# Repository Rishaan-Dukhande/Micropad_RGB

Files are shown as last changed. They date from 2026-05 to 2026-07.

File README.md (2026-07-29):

# Rishaan RGB micro hackpad

The RGB micro is a 2 key macropad with a joystick, an OLED Display, and one RGB LED - giving the user multiple ways to change an LED to any color and brightness they want! This serves as the first PCB I have created and is a great introductory project to develop PCB, CAD, and firmware skills for engineering! I created this project to develop these skills and enhance my engineering skills and knowledge. I have used RGBs and there is a color game called hues and cues, and this LED allows you to access a pallet just like the game, but in real life! Features, Images, and steps to recreate this project are listed below.
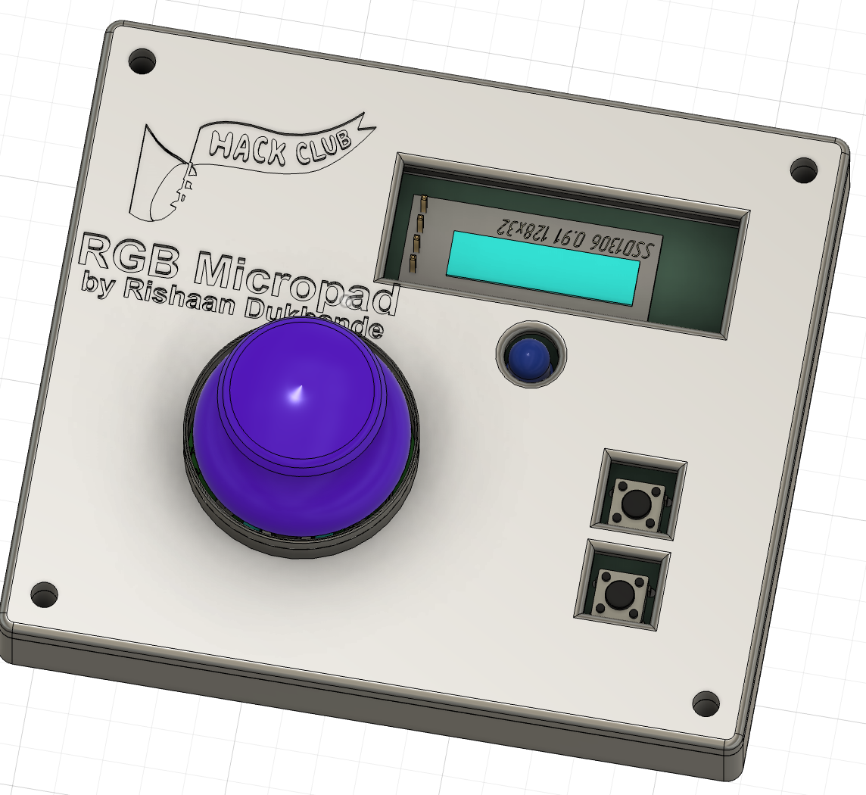
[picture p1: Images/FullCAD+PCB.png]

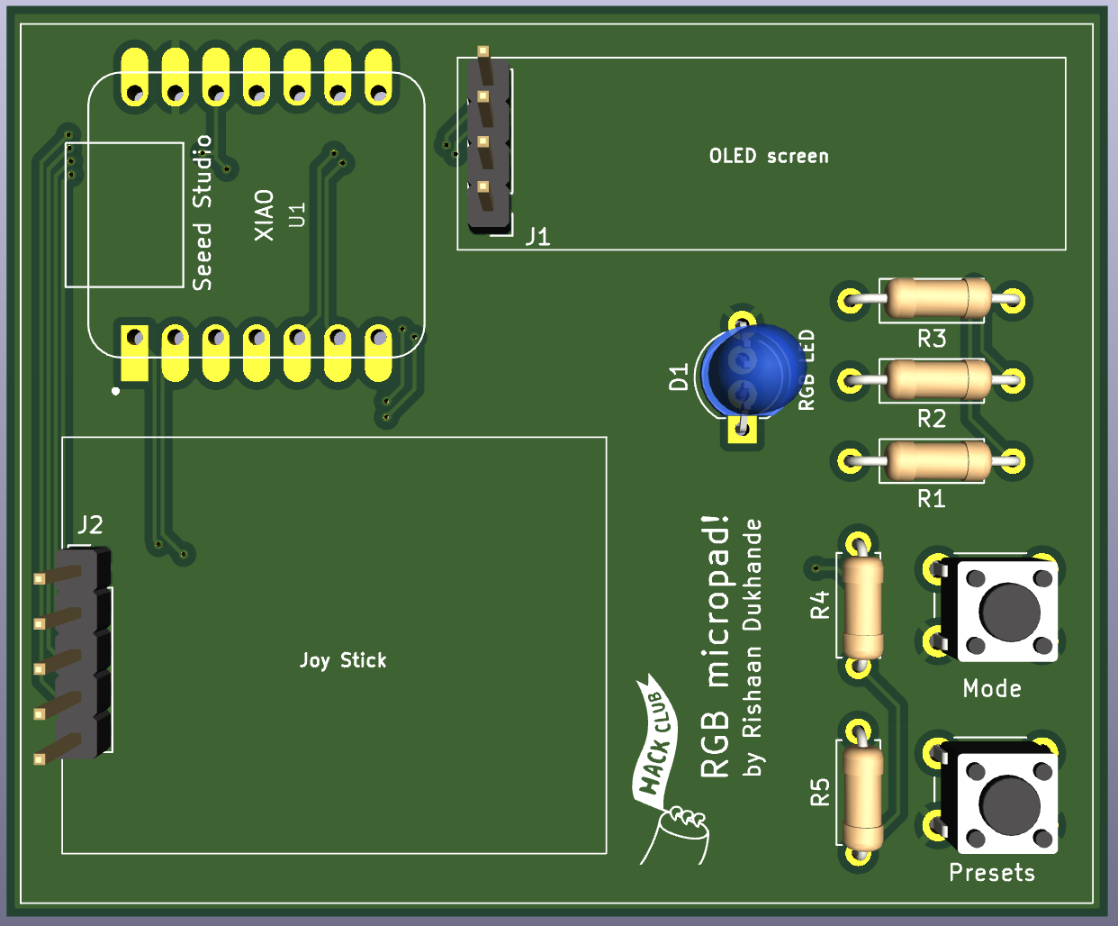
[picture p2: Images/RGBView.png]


# Demo

Video Title (https://www.youtube.com/watch?v=ukX_e_Ombvo)

## Features:

* Portable 3D case with openings for components and USB connection
* Seeeduino XIAO SAMD21 controller
* 1 RGB LED for bright color display
* 2 tactile switch buttons for modes and presets
* Small OLED screen that displays the current RGB value in real time.
* Joystick for smooth & dynamic brightness and color control

## How it works

The RGB Micropad is a mini RGB LED controller. The joystick navigates 
a full 360° color wheel — pushing in any direction changes the LED to 
that hue in real time. SW1 toggles between Color mode and Brightness 
mode, while SW2 cycles through 8 color presets. Pressing the joystick 
button activates Saturation mode, letting the user dial between vivid 
and pastel tones and creating a larger array of colors for the LED to
display. The OLED screen shows the current mode, color name, 
RGB values, and brightness percentage at all times.

## PCB

Here's my PCB! Kicad was used to create both the schematic and layout of the pcb.

### Schematic

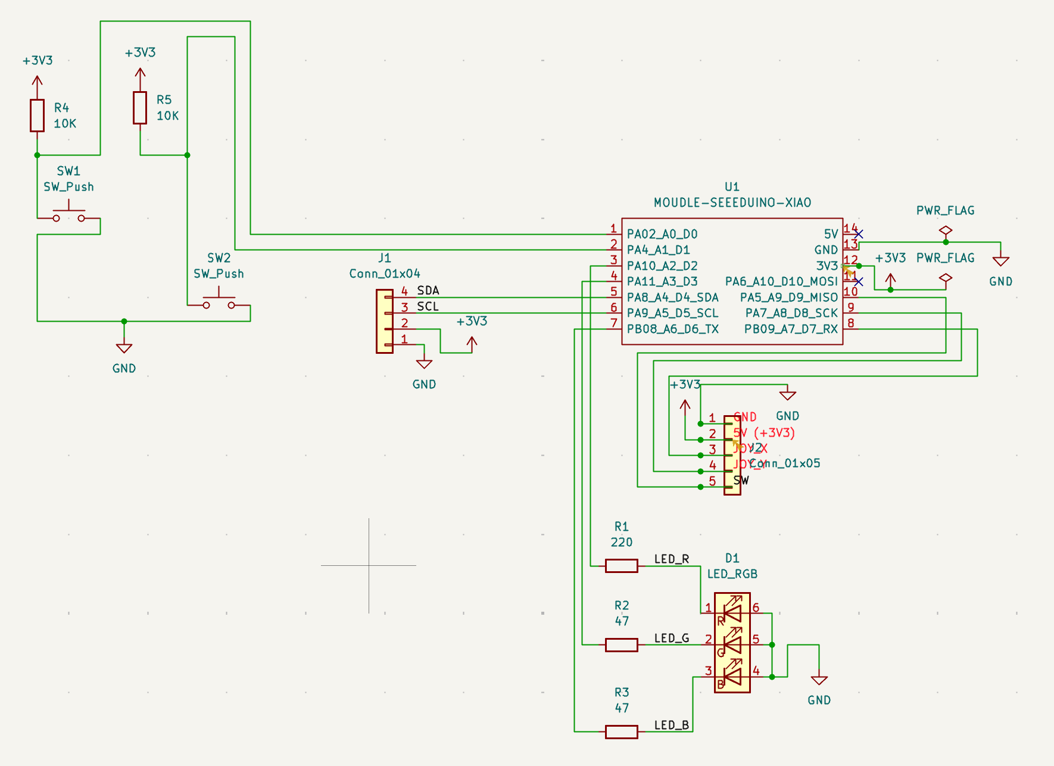
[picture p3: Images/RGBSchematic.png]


### PCB

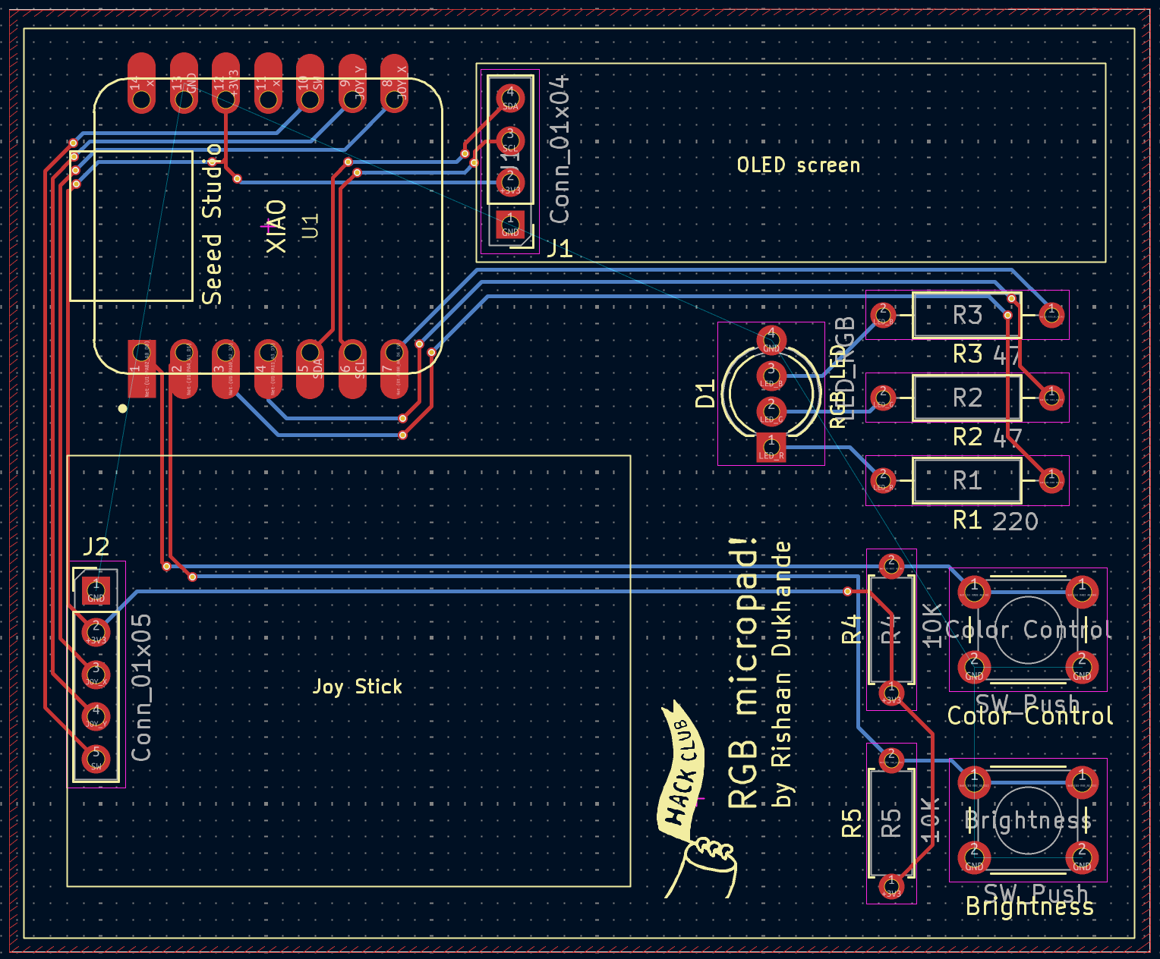
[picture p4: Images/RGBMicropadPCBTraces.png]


The 1x4 connector on the top is for connecting the Oled Screen (SSD1306 0.91" OLED I2C 128x32) The 1x5 connector on the bottom center of the pcb is for connecting the controling joystick

## Sizes and PCB Info

* Board size: 56.95mm x 68.85mm
* 2 layer PCB
* Designed in KiCad 9.0

## Firmware
Written in CircuitPython. The main.py file enables the user to have the following controls:
* SW1 → Toggle between Color mode and Brightness mode
* SW2 → Cycle through 8 color presets
* Joystick button → Toggle saturation mode on/off
* Joystick X/Y → Navigate color wheel (Color mode) or adjust brightness (Brightness mode)
* OLED display → Shows current mode, color name, RGB values, and brightness %

## BOM:

Here is everything used in the RGB micro hackpad. Note that most of the prices come in sets because components cost the least when they are bought in bulk.

| **Qty** | **Component** | **Note** | **Price** |
|:--:|:--:|:--:|:--:|
| 1 | Seeeduino XIAO SAMD21 | Main processor | [~$5.40](https://www.seeedstudio.com/Seeeduino-XIAO-Arduino-Microcontroller-SAMD21-Cortex-M0+-p-4426.html) |
| 1 | SSD1306 0.91" OLED I2C 128x32 | Displays brightness and color info | [~$7.99](https://www.amazon.com/gp/product/B079BN2J8V/ref=ewc_pr_img_4?smid=A1WZRPJ0MN58A9&th=1) |
| 1 | Analog thumbstick joystick module KY-023 | Joystick control | [~$7.99](https://www.amazon.com/gp/product/B0GWQ6KXYP/ref=ewc_pr_img_3?smid=A3S807LE0L63AP&psc=1) |
| 1 | RGB LED 5mm common cathode | LED that is being controlled | [~$8.99 (100 pack)](https://www.amazon.com/gp/product/B01C3ZZT8W/ref=ewc_pr_img_1?smid=A14FP9XIRL6C1F&th=1) |
| 2 | 10KΩ resistor | Pull up resistors for buttons | [~$8.99 (kit)](https://www.amazon.com/Elegoo-Values-Resistor-Assortment-Compliant/dp/B072BL2VX1) |
| 1 | 220Ω resistor | Red LED pin | [included in resistor kit](https://www.amazon.com/Elegoo-Values-Resistor-Assortment-Compliant/dp/B072BL2VX1) |
| 2 | 47Ω resistor | Green and Blue LED pins | [included in resistor kit](https://www.amazon.com/Elegoo-Values-Resistor-Assortment-Compliant/dp/B072BL2VX1) |
| 2 | Tactile push button 6x6mm | Control modes for joystick control | [~$5.99 (pack)](https://www.amazon.com/gp/product/B07VSNN9S2/ref=ewc_pr_img_2?smid=AJJYA8M5YMCKV&psc=1) |
| 1 | 2.54mm pin header 1x04 | OLED screen connector | [~$6.99 (pack)](https://www.amazon.com/MCIGICM-Header-2-54mm-Arduino-Connector/dp/B07PKKY8BX) |
| 1 | 2.54mm pin header 1x05 | Joystick connector | [included in pack above](https://www.amazon.com/MCIGICM-Header-2-54mm-Arduino-Connector/dp/B07PKKY8BX) |

## Steps to Reproduce

### Parts
Order the parts in the Bill of Materials. These will be soldered on the PCB manually later on (unless specified in JLCPCB)

### PCB Manufacturing
1. Download PCB/gerbers.zip (in PCB folder of repository)
2. Upload to JLCPCB or PCBWay (You can get grants from hackclub if you edit the PCB before upload!)
3. Place the order - remember to pick the least expensive shipping!

### Assembly

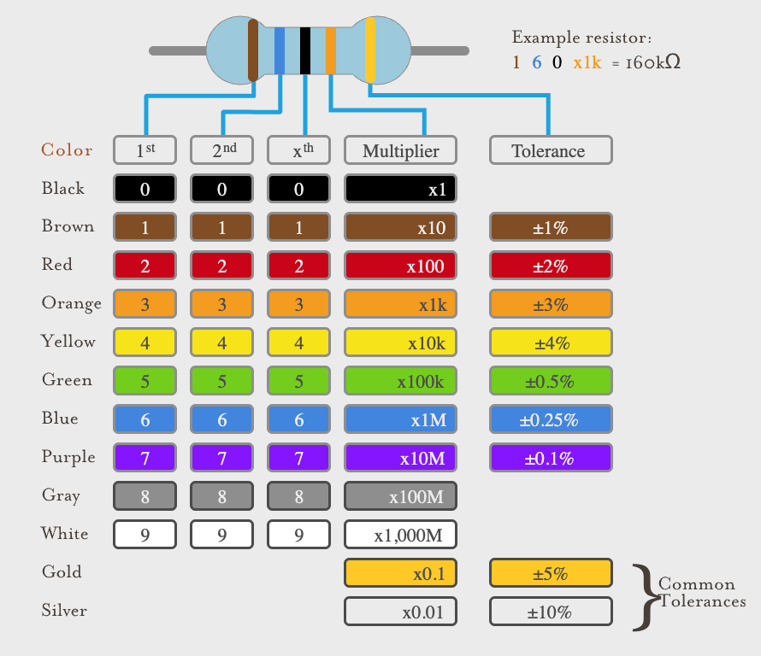
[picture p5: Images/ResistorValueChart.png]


1. Solder resistors R1-R5 onto the PCB. Utilize the following resistor values
2. Refer to the table above to read resistor values before incorporating them.
The table below has the resistor values with their placement on the PCB.

| **R#** | **Value** |
|:--:|:--:|
| R1 | 220Ω |
| R2 | 47Ω |
| R3 | 47Ω |
| R4 | 10KΩ |
| R5 | 10KΩ |
  
3. Solder RGB LED into the D1 slot on the PCB
4. Solder tactile switches SW1 and SW2.
5. Solder 5 pin header into the slot for the Joystick
6. Solder 4 pin header into the slot for the OLED screen
7. Solder XIAO SAMD21 on the top left of the board

### Flashing Instructions (Get firmware onto the PCB)
1. Copy or download the firmware as a .ino file and open it in arduino IDE
2. Use a USB-C transfer cable and plug it into the seedunio XAMD 21 and a computer
3. Upload the code using arduino IDE
4. The RGB Micropad will automatically begin to work (it can be plugged in directly to power)

### Verify your RGB Micropad works!
1. Plug in via USB (either computer of any electricity source)
2. OLED should show RGB Micropad splash screen
3. Move joystick to change LED color or brightness (depends on the mode you are on)
4. Press SW1 to toggle between modes!
   Mode 1: Color
   Mode 2: Brightness
5. Press SW2 to cycle through preset colors for LED
6. Press Joystick button to toggle saturation mode (This is an advanced mode for an additional array of colors)

## AI Usage
AI was used during the project as a step-by-step guide. The firmware was also written by AI.

## Devlog
### Session 1 — Schematic Design
The schematic was designed in Kicad. This included the following components:
1) XIAO SAMD21
2) RGB LED
3) Joystick module
4) OLED screen
5) Two tactile buttons

### Session 2 — PCB Layout
Note) This takes about 2 hrs for beginners
1) Layout of all components (If you are replicating, be creative and change locations of components).
2) Added GND copper pour so I don't have to route GND pins of every component
3) Routed the PCB connections between XIAO board and components
4) Created Silkscreen for aesthetics including Hack Club logo and component labels.

### Session 3 - Error with pullup resistors
1) Edited schematic by adding 10KΩ pullup resistors for both tactile switches
2) Used Ohm's law to calculate resistor values for RGB LED pins
   a) Blue and Green pins receive 47Ω resistors
   b) Red pin receives 220Ω resistors
   c) This occurs because they have different voltage requirements in order to power the color
3) Update PCB layout to include the resistors (2hrs).

### Session 4 — Firmware
1) Wrote CircuitPython firmware. This enables the PCB to have the following capabilities:
   a) Implemented color wheel for color mode control
   b) Brightness control from Joystick
   c) Mode navigation button to control both color and brightness with one Joystick
   d) Easily use joystick to change LED characteristics

### Session 5 — Case Design
Designed sandwich mount 3D-case in Fusion 360. The sandwich mount design can be found as the 5th mount in this [Different keyboard mounts](https://www.monsgeek.com/blog/comprehensive-guide-to-keyboard-mounting-styles/) document.

#### Bottom case (1hr)
1) Created bottom case with 0.4 mm clearance for PCB on all sides
2) Added 10mm thick walls all around board and 3.2mm diameter mounting holes
#### Top case (1 hr)
3) Measured placement of components on PCB and created openings
4) Added fillets to strengthen design and make it look good
5) Added project name, author, and hackclub svg logo

### Session 6 - README and Github Polish
1) Reviewed current github
2) Added devlog, images, and project info to the README.

### session 7 - Assembly (3-4 hrs)
1) Soldered components to the PCB
2) Re-designed the case to better fit PCB
3) Created Demo Video

## Extra stuff

I am ready to create more complex hackpads. Through this project, I was able to gain PCB making skills and refine my CAD skills. I am now confident that I can create electronic projects at a much faster pace with the use of these digital designing tools. If you have any project recommendations, please feel free to share them!

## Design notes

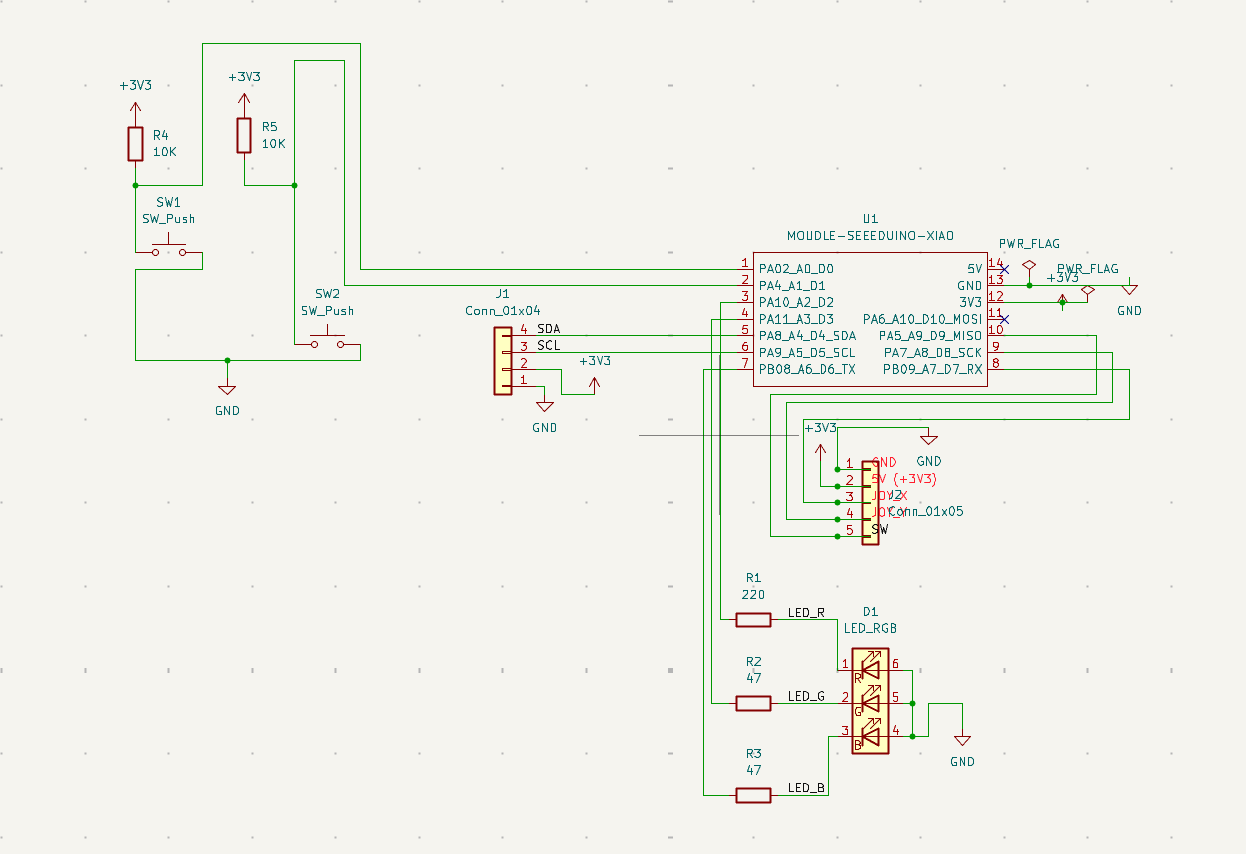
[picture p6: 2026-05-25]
Images/RGBMicropadSchematic.png

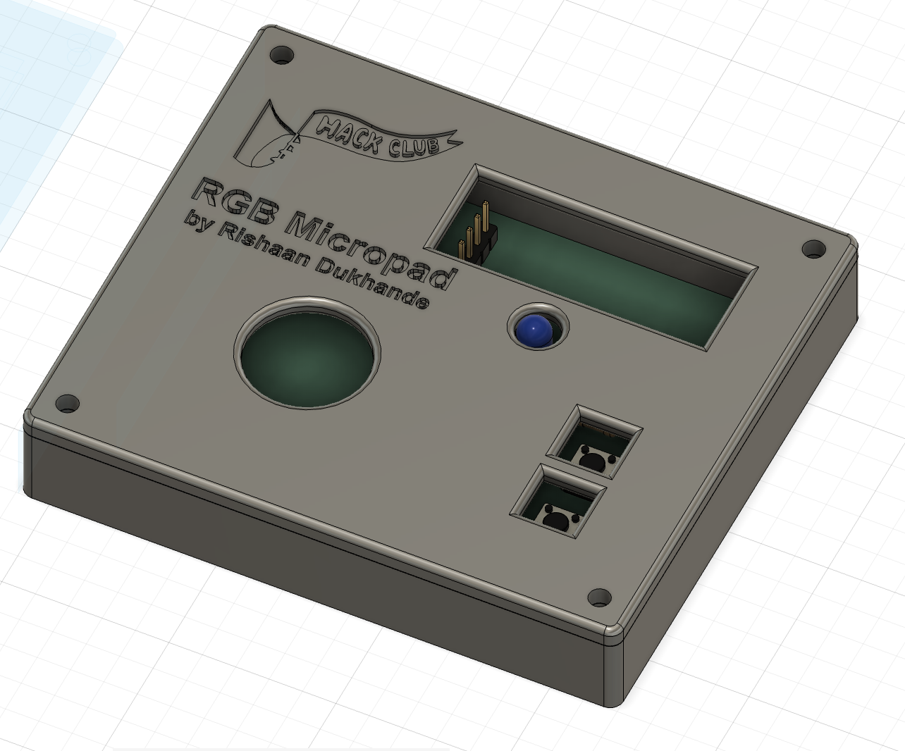
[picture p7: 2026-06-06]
Images/V1FullCase.png

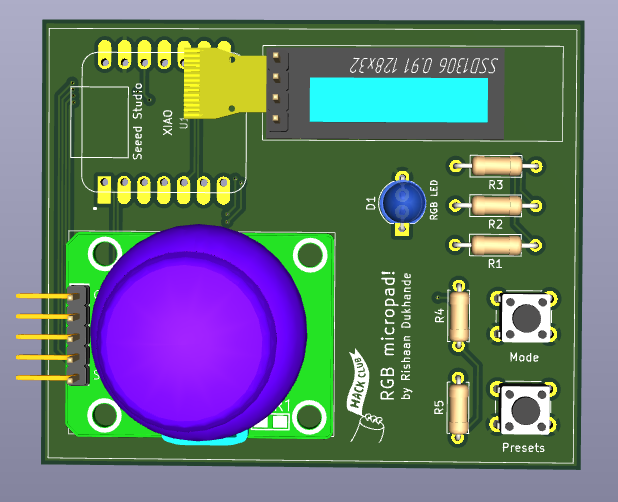
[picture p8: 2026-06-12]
Images/PCB+modules.png

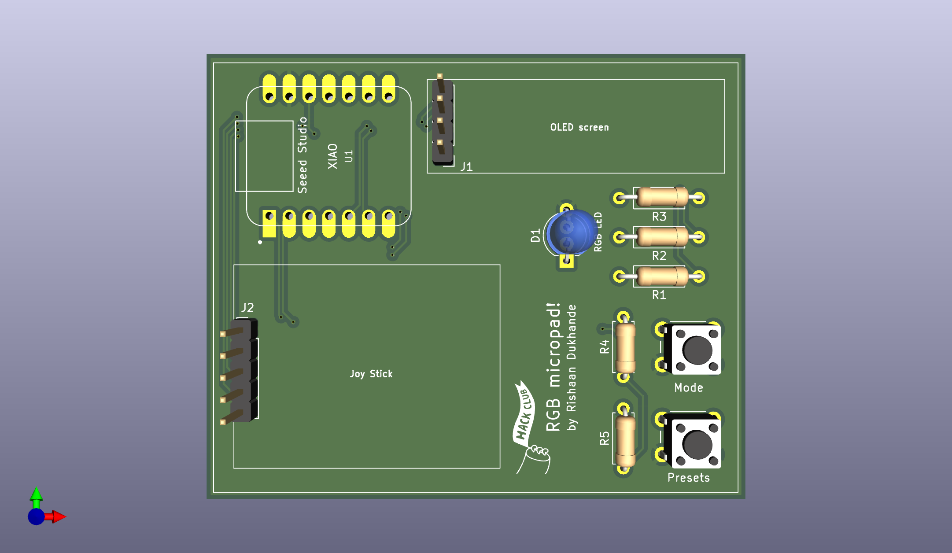
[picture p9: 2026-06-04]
PCB/rgbPCB.png

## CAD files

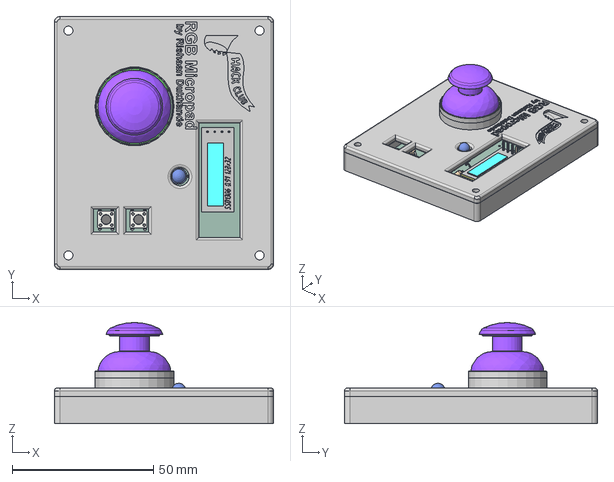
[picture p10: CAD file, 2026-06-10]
CAD/micropad_combined.step
77.8 x 89.7 x 35.8 mm

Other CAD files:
CAD/rgb_micropad_case.f3z

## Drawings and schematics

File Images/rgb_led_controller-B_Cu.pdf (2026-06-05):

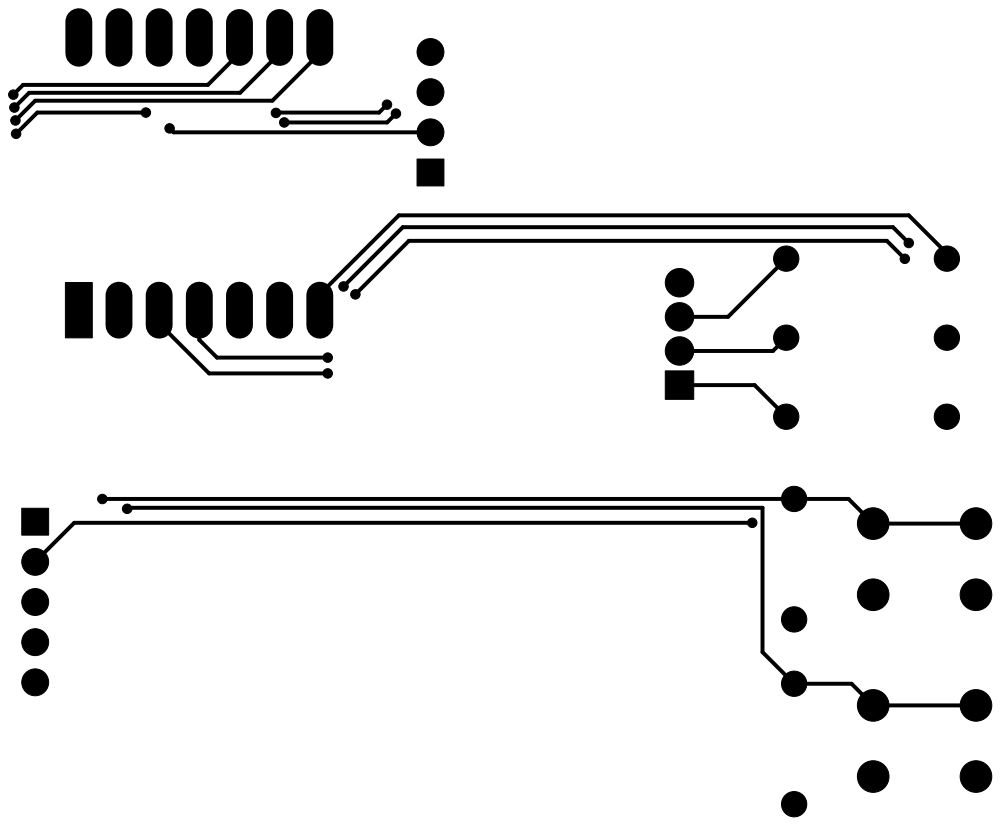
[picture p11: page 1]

Id: 2/10 Title: File: rgb_led_controller.kicad_pcb Sheet:

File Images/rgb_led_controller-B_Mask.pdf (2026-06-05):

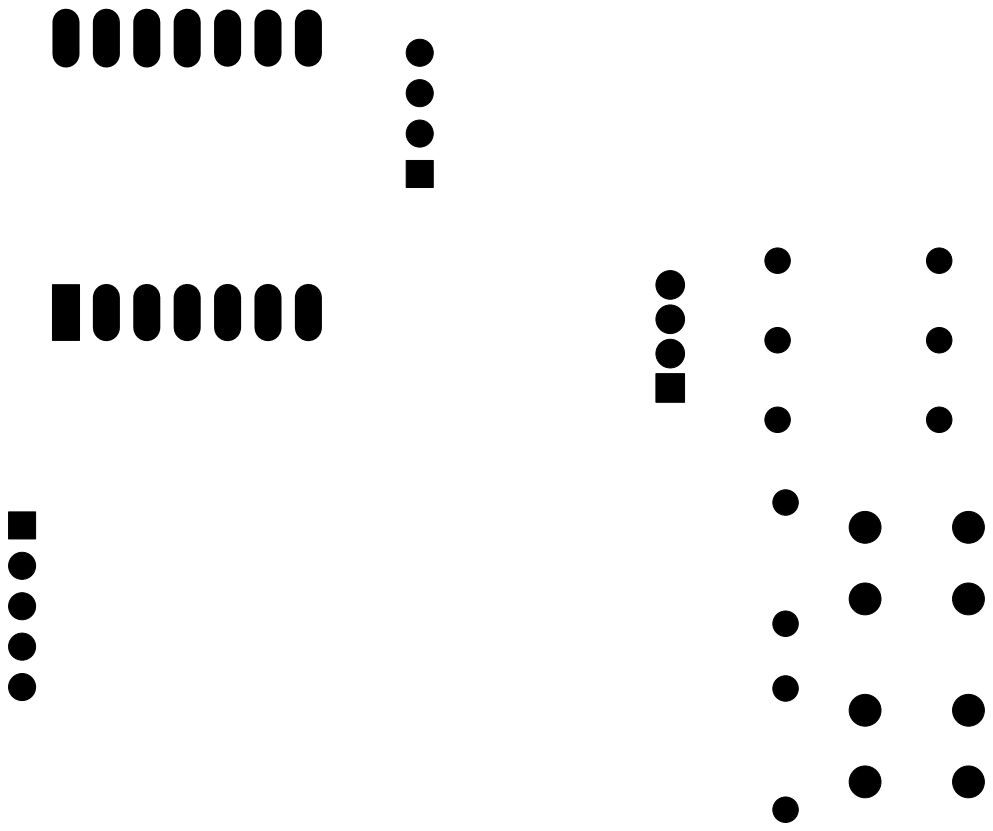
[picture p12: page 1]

Id: 8/10 Title: File: rgb_led_controller.kicad_pcb Sheet:

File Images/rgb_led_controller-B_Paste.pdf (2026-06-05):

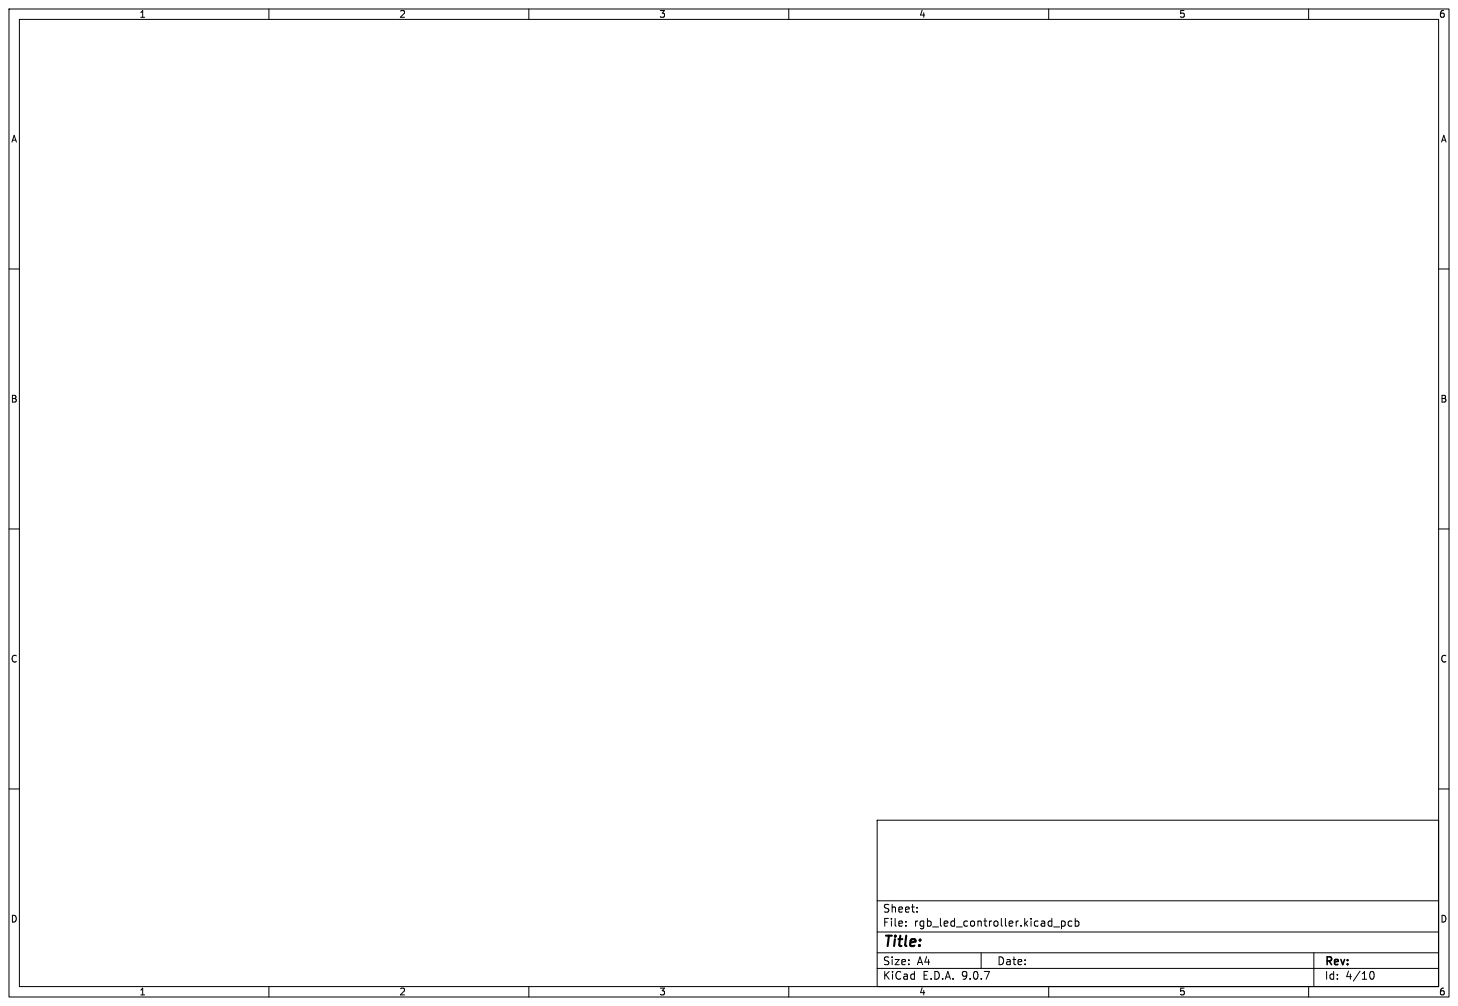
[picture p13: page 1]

Id: 4/10 Title: File: rgb_led_controller.kicad_pcb Sheet:

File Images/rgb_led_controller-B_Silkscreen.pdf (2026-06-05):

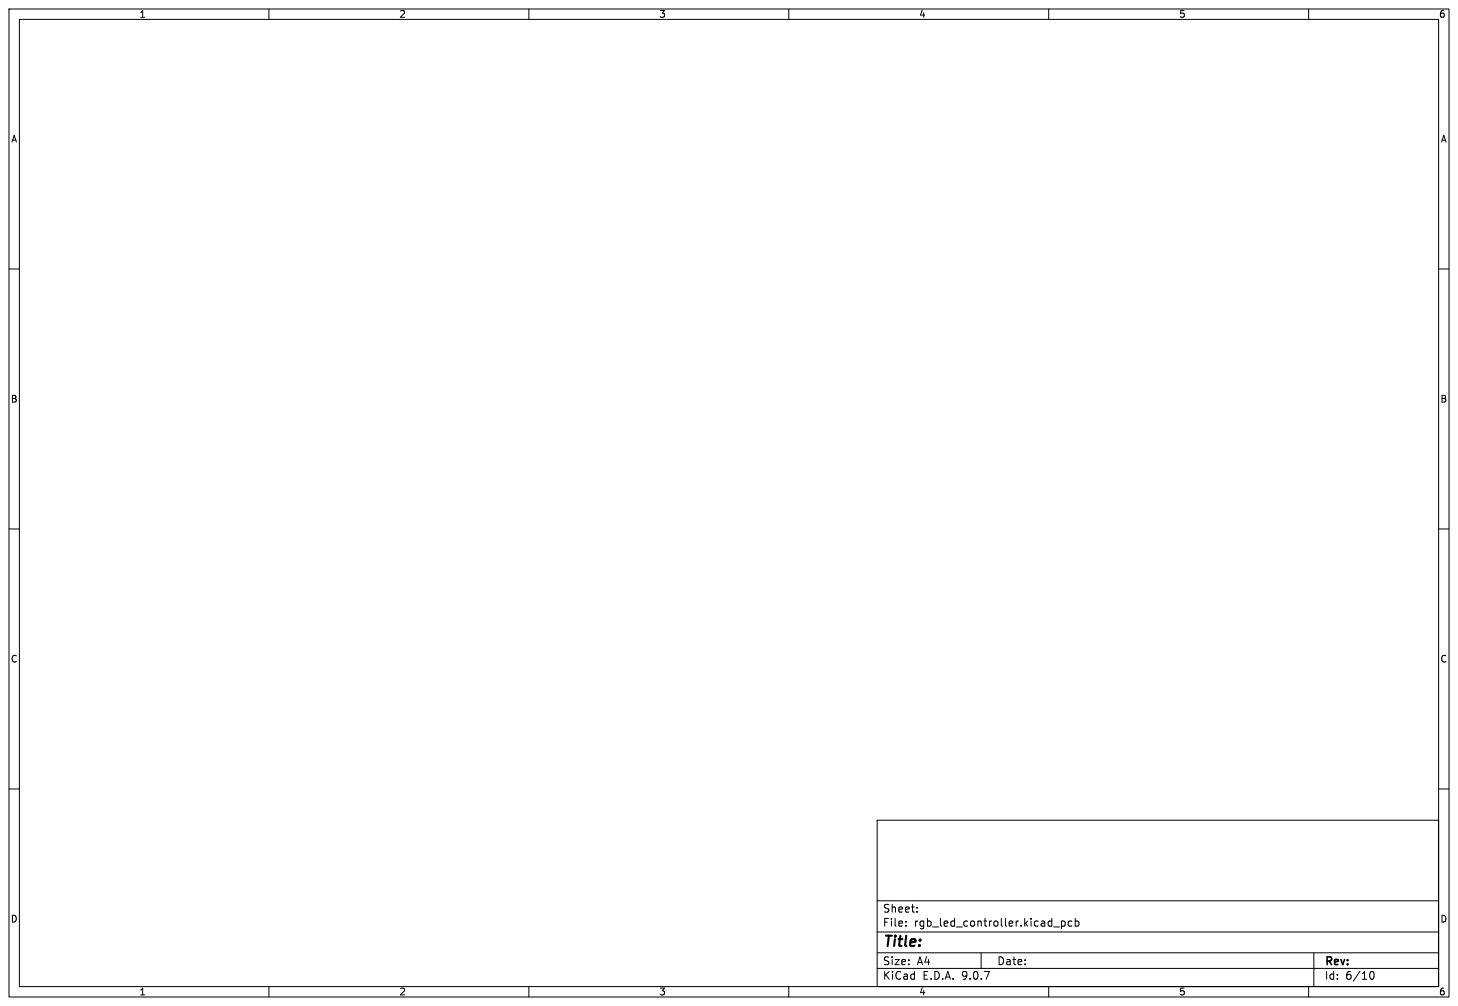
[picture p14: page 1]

Id: 6/10 Title: File: rgb_led_controller.kicad_pcb Sheet:

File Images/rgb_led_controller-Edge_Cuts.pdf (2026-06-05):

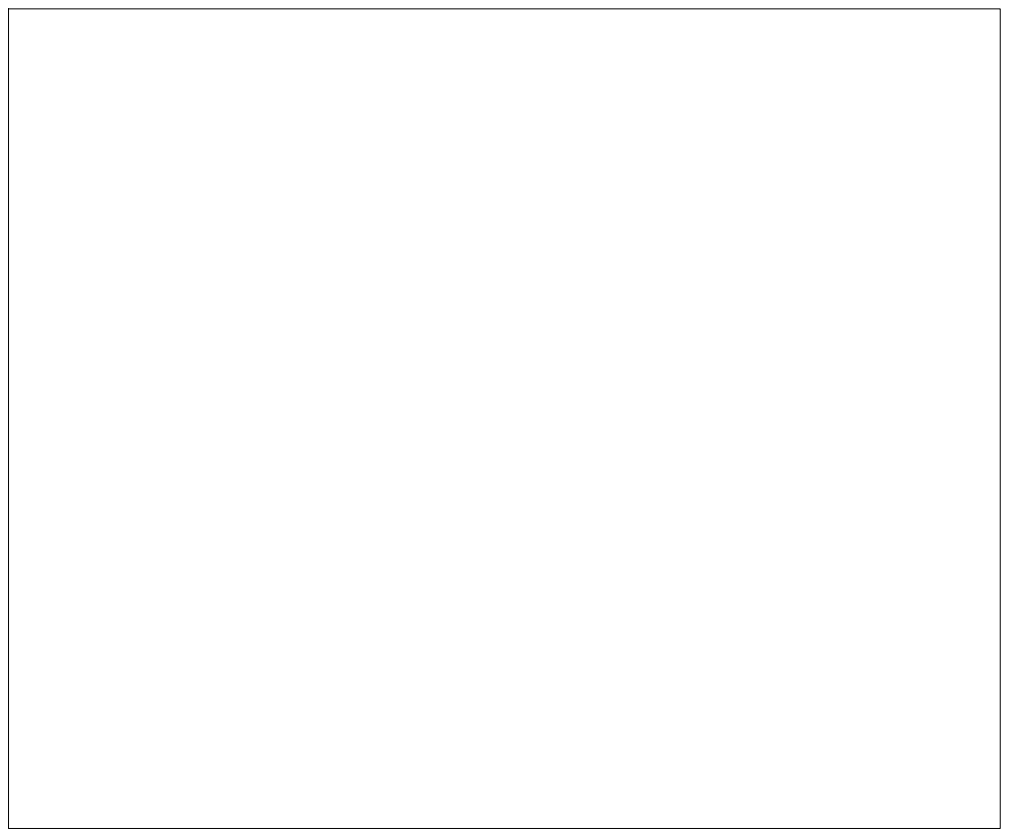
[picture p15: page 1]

Id: 9/10 Title: File: rgb_led_controller.kicad_pcb Sheet:

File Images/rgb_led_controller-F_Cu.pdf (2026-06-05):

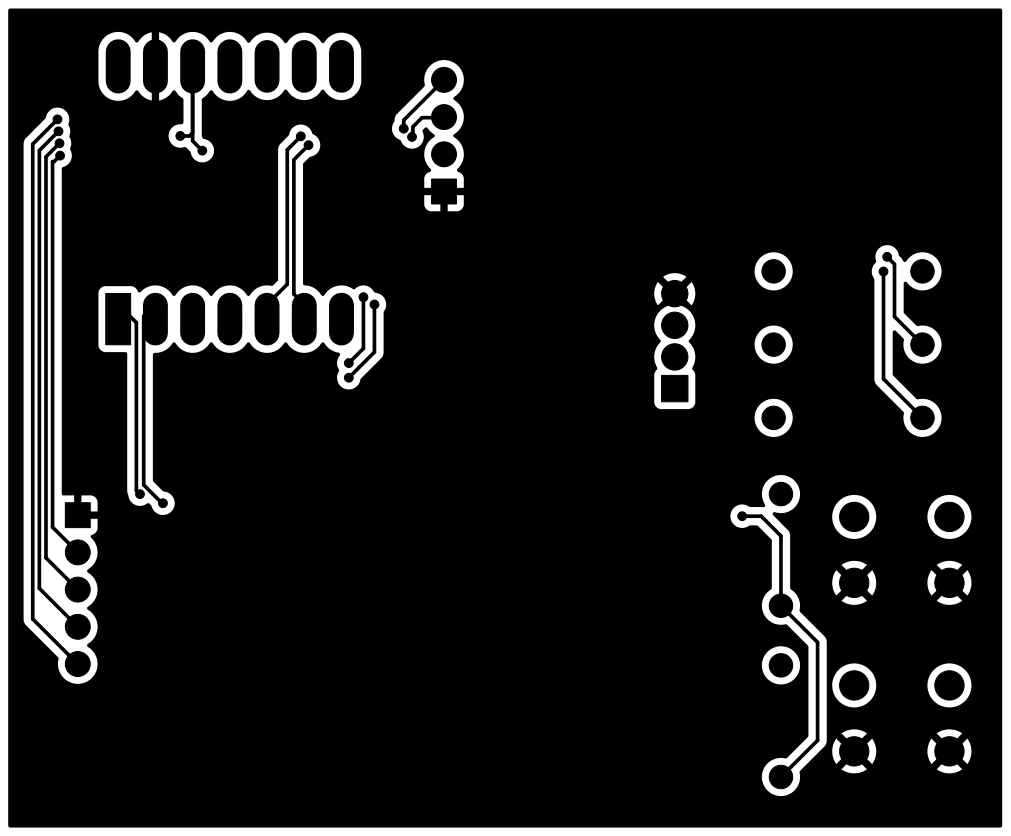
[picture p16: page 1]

Id: 1/10 Title: File: rgb_led_controller.kicad_pcb Sheet:

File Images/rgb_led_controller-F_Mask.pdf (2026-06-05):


Id: 7/10 Title: File: rgb_led_controller.kicad_pcb Sheet:

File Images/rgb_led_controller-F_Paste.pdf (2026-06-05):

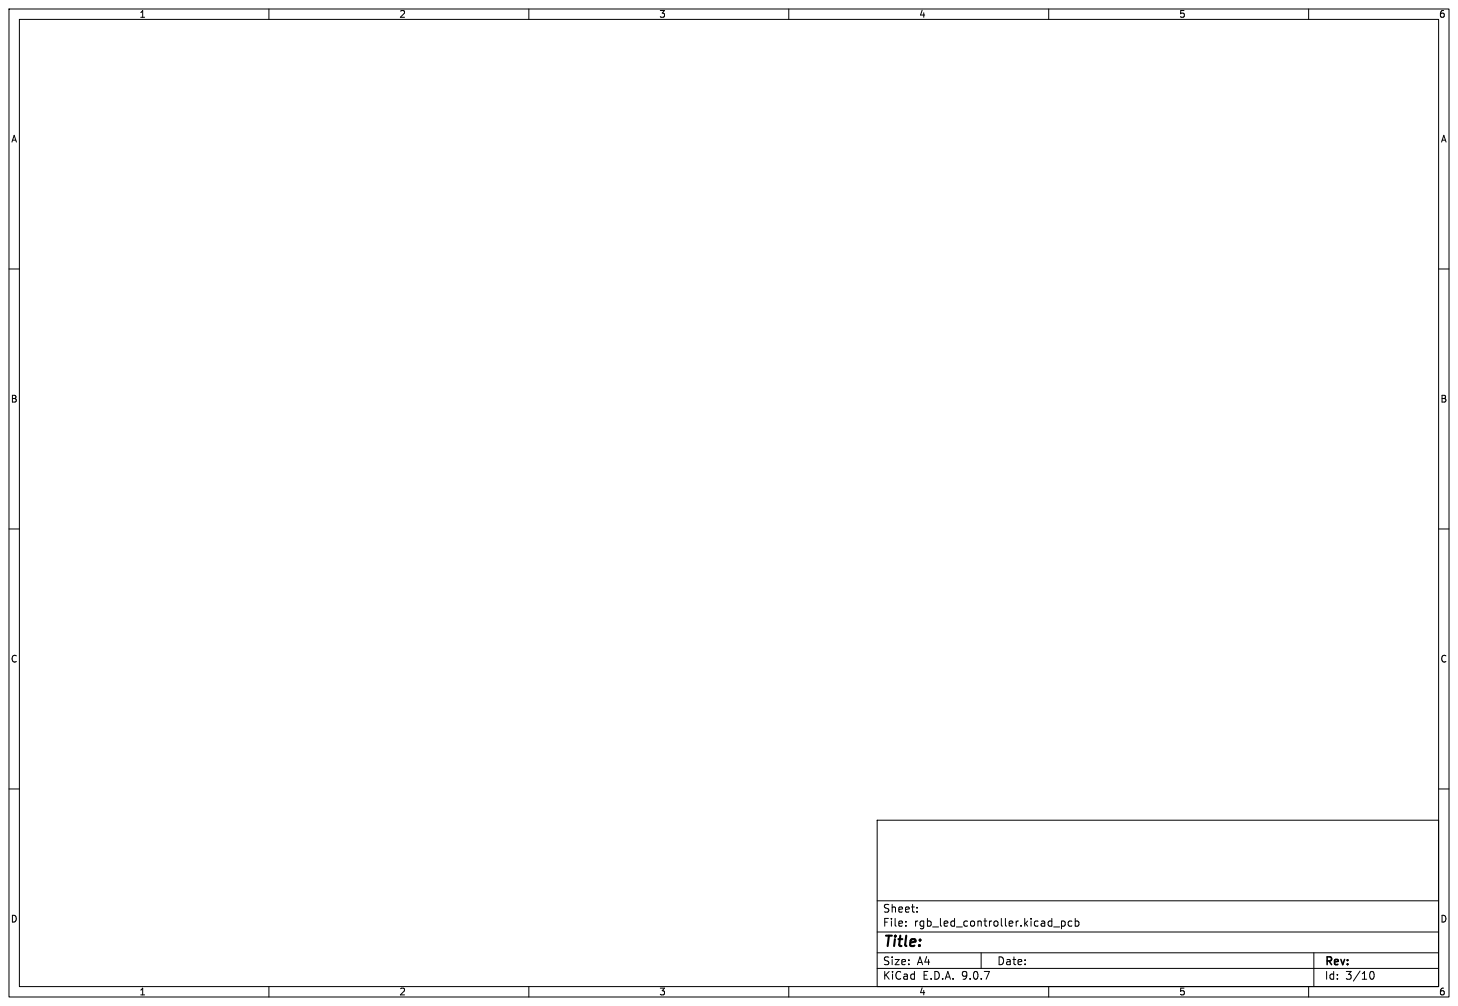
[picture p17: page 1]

Id: 3/10 Title: File: rgb_led_controller.kicad_pcb Sheet:

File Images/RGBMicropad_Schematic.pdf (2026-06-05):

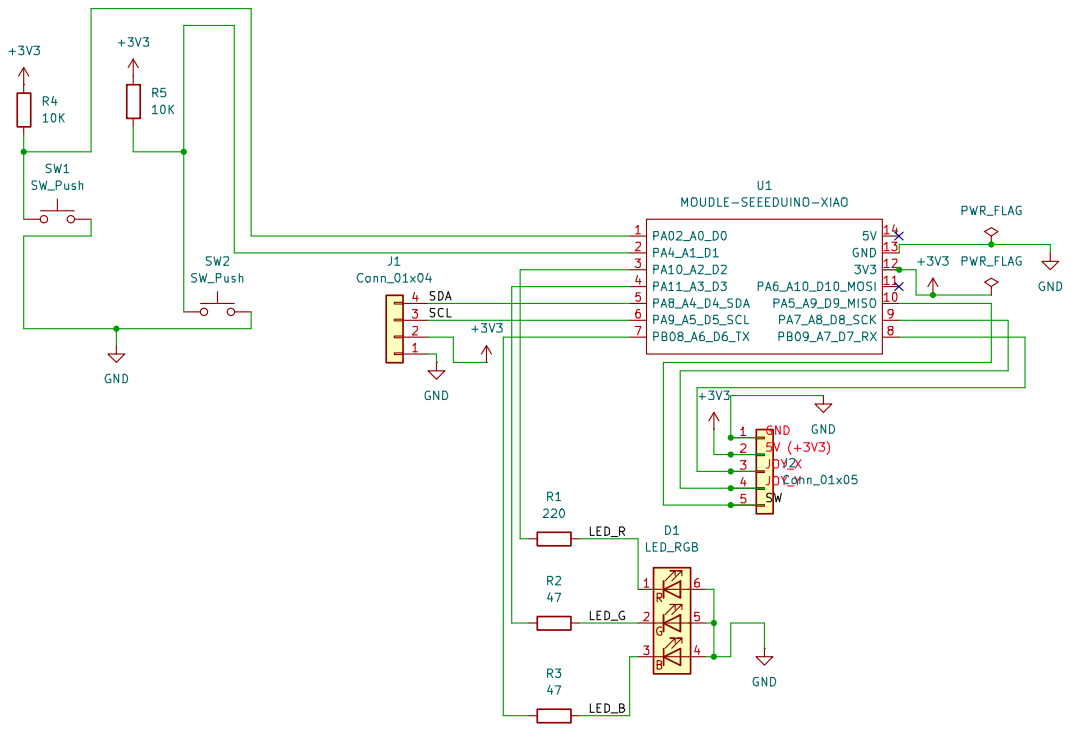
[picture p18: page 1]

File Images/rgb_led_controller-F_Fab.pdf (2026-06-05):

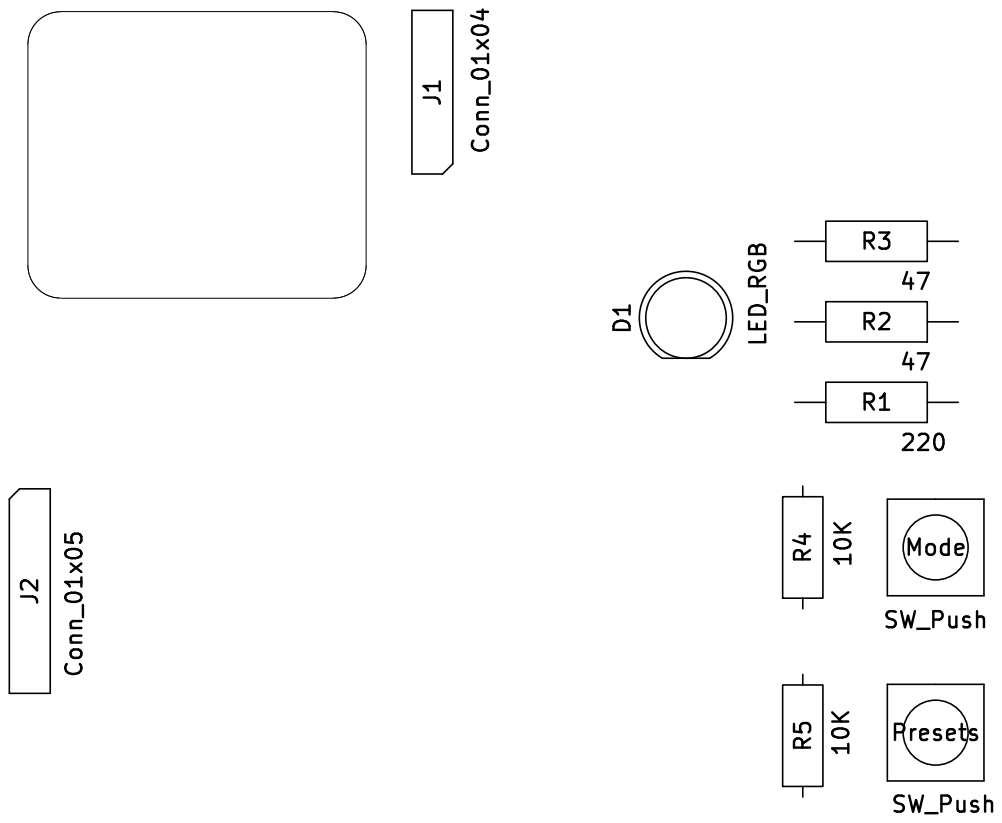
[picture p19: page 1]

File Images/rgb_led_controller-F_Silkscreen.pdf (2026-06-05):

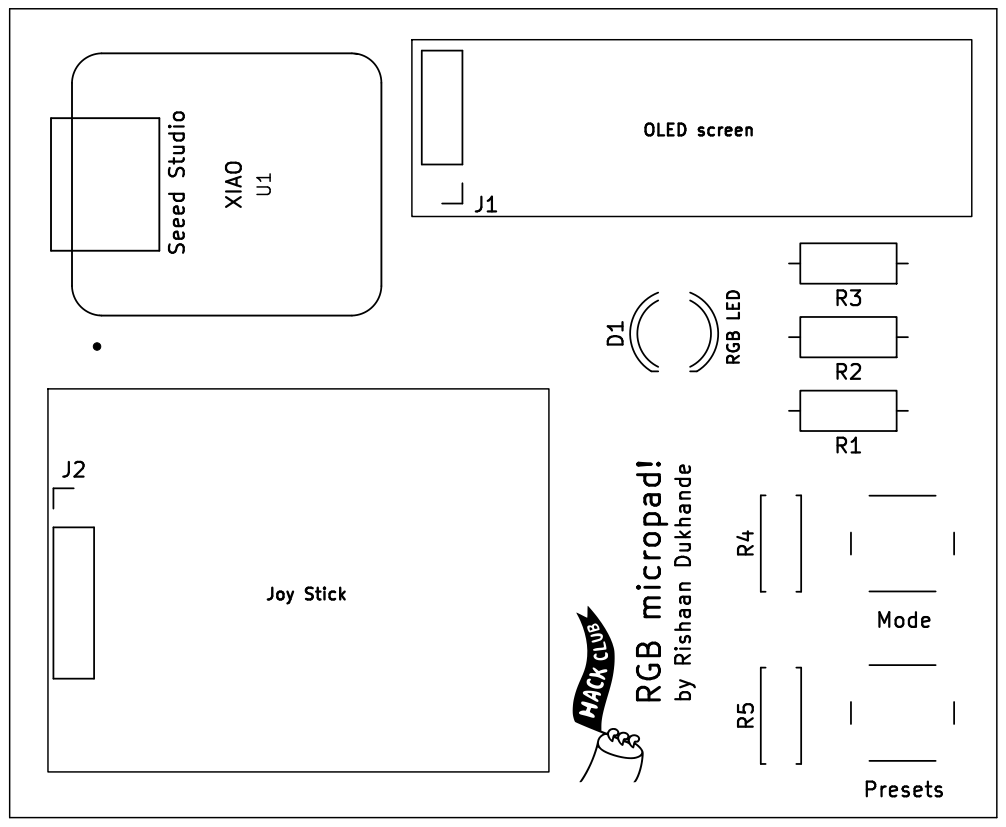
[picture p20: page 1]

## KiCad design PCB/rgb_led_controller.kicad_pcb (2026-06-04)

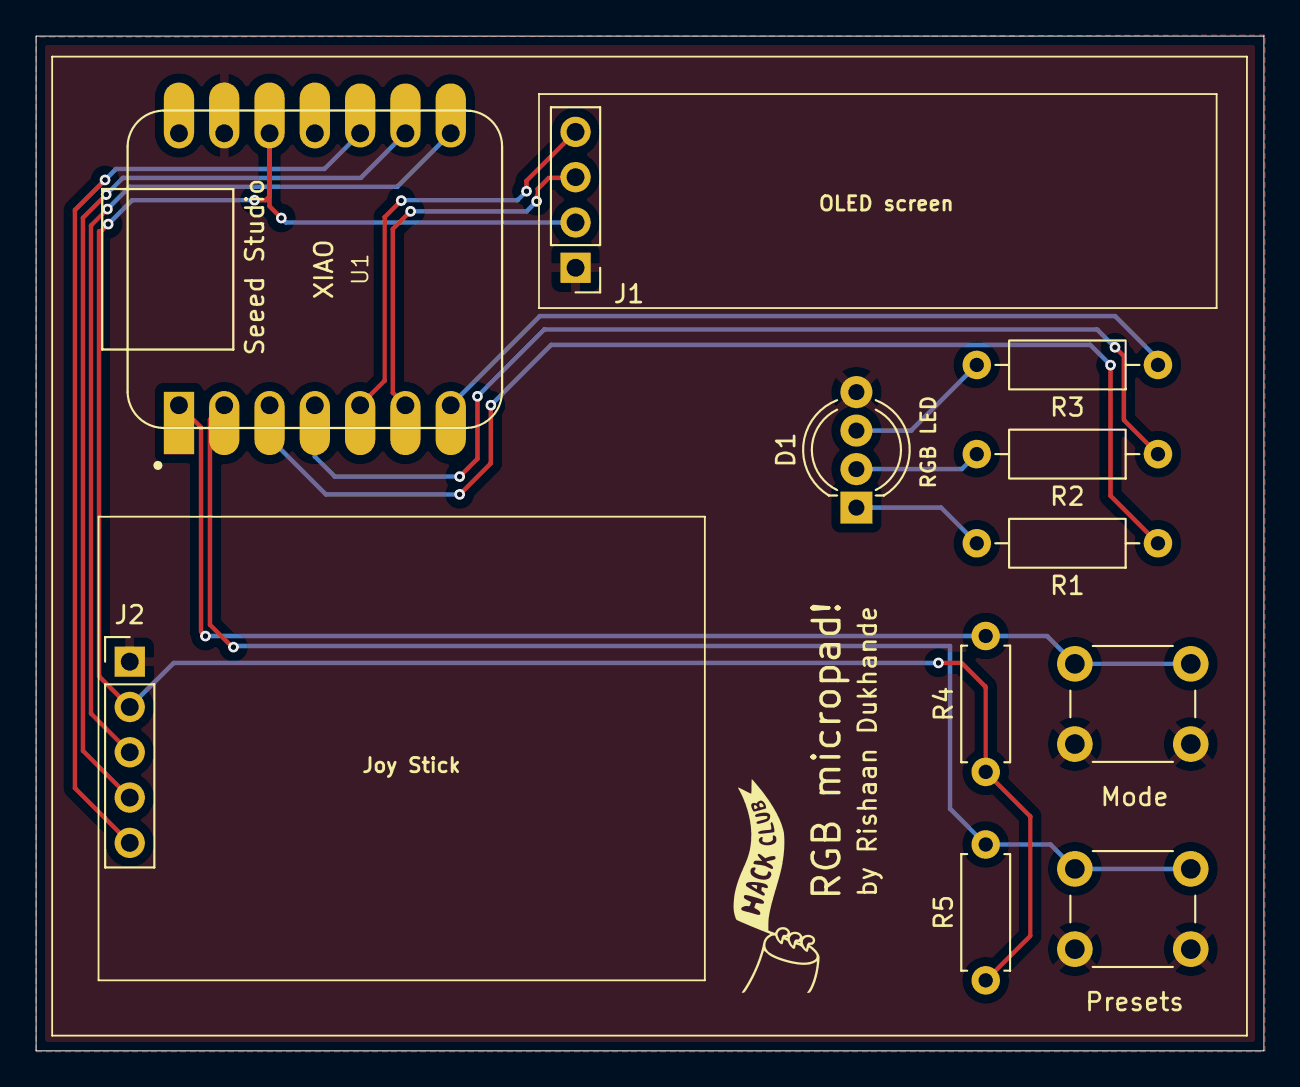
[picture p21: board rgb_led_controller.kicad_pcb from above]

Board: 2 copper layers, 68.8 x 56.9 mm, 12 parts (0 on the bottom side), 15 nets.

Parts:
D1: LED_RGB; LED_D5.0mm-4_RGB_Wide_Pins
J1: Conn_01x04; PinHeader_1x04_P2.54mm_Vertical
J2: Conn_01x05; PinHeader_1x05_P2.54mm_Vertical
Mode: SW_Push; SW_PUSH_6mm
Presets: SW_Push; SW_PUSH_6mm
R1: 220; R_Axial_DIN0207_L6.3mm_D2.5mm_P10.16mm_Horizontal
R2, R3: 47; R_Axial_DIN0207_L6.3mm_D2.5mm_P10.16mm_Horizontal
R4, R5: 10K; R_Axial_DIN0207_L6.3mm_D2.5mm_P7.62mm_Horizontal
U1: MOUDLE-SEEEDUINO-XIAO; XIAO-Generic-Hybrid-14P-2.54-21X17.8MM
logo: LOGO

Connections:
+3V3: J1.2, J2.2, R4.1, R5.1, U1.12 (3V3)
/JOY_X: J2.3, U1.8 (PB09_A7_D7_RX)
/JOY_Y: J2.4, U1.9 (PA7_A8_D8_SCK)
/LED_B: D1.3 (BK), R3.2
/LED_G: D1.2 (GK), R2.2
/LED_R: D1.1 (RK), R1.2
/SCL: J1.3, U1.6 (PA9_A5_D5_SCL)
/SDA: J1.4, U1.5 (PA8_A4_D4_SDA)
/SW: J2.5, U1.10 (PA5_A9_D9_MISO)
GND: D1.4 (BA), J1.1, J2.1, Mode.2, Presets.2, U1.13 (GND)
unnamed: Mode.1, R4.2, U1.1 (PA02_A0_D0)
unnamed: Presets.1, R5.2, U1.2 (PA4_A1_D1)
unnamed: R1.1, U1.3 (PA10_A2_D2)
unnamed: R2.1, U1.4 (PA11_A3_D3)
unnamed: R3.1, U1.7 (PB08_A6_D6_TX)

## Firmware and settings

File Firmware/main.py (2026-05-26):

# ─────────────────────────────────────────────────────────────────────────────
# RGB Micropad Firmware
# Author:      Rishaan Dukhande
# Description: Controls an RGB LED via joystick and buttons
#
# CONTROLS:
#   SW1 (D0)        → Toggle between COLOR mode and BRIGHTNESS mode
#   SW2 (D1)        → Cycle through color presets
#   Joystick SW     → Toggle saturation mode on/off
#   Joystick X/Y    → COLOR mode:      navigate color wheel (hue)
#                     BRIGHTNESS mode: Y axis controls brightness
#                     SAT mode:        Y axis controls saturation
#
# OLED DISPLAY:
#   Line 1 → Current mode name
#   Line 2 → Current color name
#   Line 3 → RGB values + brightness % (or saturation % in sat mode)
#
# REQUIRED LIBRARIES (copy to CIRCUITPY/lib/ folder on your XIAO):
#   - adafruit_ssd1306
#   - adafruit_bus_device
#   - adafruit_framebuf
# ─────────────────────────────────────────────────────────────────────────────

import board        # Gives us access to pin names like board.D0, board.SDA
import busio        # Handles I2C communication for the OLED
import time         # For delays and timestamps
import math         # For atan2 (angle calculation for color wheel)
import analogio     # For reading analog joystick values (0-65535)
import digitalio    # For reading digital button states (True/False)
import pwmio        # For PWM output to control LED brightness
import adafruit_ssd1306  # OLED display library from Adafruit


# ─────────────────────────────────────────────────────────────────────────────
# PIN SETUP
# ─────────────────────────────────────────────────────────────────────────────

# RGB LED pins — PWM allows us to control brightness by varying duty cycle
# frequency=1000 means the pin switches on/off 1000 times per second
# This is fast enough that the eye perceives it as a steady dimmed light (PWM)
led_red   = pwmio.PWMOut(board.D2, frequency=1000)  # Red channel   → PA10
led_green = pwmio.PWMOut(board.D3, frequency=1000)  # Green channel → PA11
led_blue  = pwmio.PWMOut(board.D6, frequency=1000)  # Blue channel  → PB08

# SW1 — Mode toggle button (Color ↔ Brightness)
# Pull.UP means the pin is held HIGH (True) by default
# When button is pressed, it connects to GND → reads False
sw1 = digitalio.DigitalInOut(board.D0)
sw1.direction = digitalio.Direction.INPUT
sw1.pull = digitalio.Pull.UP

# SW2 — Preset cycle button
sw2 = digitalio.DigitalInOut(board.D1)
sw2.direction = digitalio.Direction.INPUT
sw2.pull = digitalio.Pull.UP

# Joystick analog axes — read voltage as 0 to 65535
# Center position reads approximately 32768
joy_x = analogio.AnalogIn(board.A7)   # Left/Right → PB09
joy_y = analogio.AnalogIn(board.A8)   # Up/Down    → PA07

# Joystick SW button — pressing the joystick stick down
joy_sw = digitalio.DigitalInOut(board.A9)
joy_sw.direction = digitalio.Direction.INPUT
joy_sw.pull = digitalio.Pull.UP

# OLED Display — communicates via I2C protocol using SDA and SCL pins
i2c = busio.I2C(board.SCL, board.SDA)
oled = adafruit_ssd1306.SSD1306_I2C(128, 32, i2c)  # 128px wide, 32px tall


# ─────────────────────────────────────────────────────────────────────────────
# CONSTANTS — values that never change during the program
# ─────────────────────────────────────────────────────────────────────────────

# Mode identifiers — stored as integers so we can compare with ==
MODE_COLOR      = 0   # Joystick controls hue on color wheel
MODE_BRIGHTNESS = 1   # Joystick Y controls brightness
MODE_NAMES      = ["COLOR MODE", "BRIGHTNESS MODE"]

# Color presets — list of tuples (name, R, G, B)
# Tuples are used here because presets should NEVER be modified at runtime
# (tuples are immutable in Python — trying to change them causes an error)
PRESETS = [
    ("Red",     255,   0,   0),
    ("Green",     0, 255,   0),
    ("Blue",      0,   0, 255),
    ("Yellow",  255, 255,   0),
    ("Cyan",      0, 255, 255),
    ("Purple",  128,   0, 128),
    ("White",   255, 255, 255),
    ("Orange",  255, 128,   0),
]

# Joystick calibration values
JOYSTICK_CENTER   = 32768  # Midpoint of 16-bit ADC range (0-65535)
JOYSTICK_DEADZONE = 4000   # Ignore movements smaller than this — prevents
                           # LED flickering when joystick is resting at center
JOYSTICK_MAX      = 32768  # Maximum deviation from center in either direction

# Debounce timing — minimum milliseconds between valid button presses
# Prevents electrical contact bouncing from registering as multiple presses
DEBOUNCE_MS = 200


# ─────────────────────────────────────────────────────────────────────────────
# STATE VARIABLES — the program's memory between loop iterations
# ─────────────────────────────────────────────────────────────────────────────

# Current operating mode (COLOR or BRIGHTNESS)
mode = MODE_COLOR

# Current position in the presets list (0 = Red, 1 = Green, etc.)
preset_index = 0

# Current brightness level: 0.0 = off, 1.0 = full brightness
brightness = 1.0

# Current saturation level: 0.0 = grey/white, 1.0 = fully vivid color
saturation = 1.0

# Whether saturation mode is active (toggled by joystick SW button)
sat_mode = False

# Current RGB values (0-255 each)
r, g, b = 255, 0, 0

# Current color name shown on OLED
color_name = "Red"

# Current hue angle on color wheel (0.0 to 360.0 degrees)
hue = 0.0

# ── Button state tracking variables ──────────────────────────────────────────
# Each button needs TWO tracking variables:
#   _last      → what the button was doing LAST loop (True = not pressed)
#   _debounce  → timestamp of the last accepted press (in milliseconds)
#
# How they work together to detect exactly ONE press:
#   not _val   → button IS pressed right now
#   _last      → button was NOT pressed last loop (catches only first loop of press)
#   time check → enough time passed since last press (handles electrical bouncing)

sw1_last       = True   # SW1 was not pressed at startup
sw2_last       = True   # SW2 was not pressed at startup
joy_sw_last    = True   # Joystick button was not pressed at startup

sw1_debounce      = 0   # Timestamp of last accepted SW1 press (0 = never pressed)
sw2_debounce      = 0   # Timestamp of last accepted SW2 press
joy_sw_debounce   = 0   # Timestamp of last accepted joystick button press


# ─────────────────────────────────────────────────────────────────────────────
# HELPER FUNCTIONS
# ─────────────────────────────────────────────────────────────────────────────

def set_led(r_val, g_val, b_val, bright=1.0):
    """
    Set LED color with brightness scaling.
    Input:  r_val, g_val, b_val = 0 to 255
            bright = 0.0 to 1.0
    Output: PWM duty cycle 0 to 65535

    Formula: duty_cycle = color_value * brightness * 257
    Why 257? Because 255 * 257 = 65535 (the max PWM value)
    """
    scale = int(bright * 257)
    led_red.duty_cycle   = int(r_val * scale)
    led_green.duty_cycle = int(g_val * scale)
    led_blue.duty_cycle  = int(b_val * scale)


def hsv_to_rgb(h, s=1.0, v=1.0):
    """
    Convert HSV color to RGB values.

    H (Hue)        = 0 to 360 degrees — position on color wheel
    S (Saturation) = 0.0 to 1.0 — 0 is grey/white, 1 is fully vivid
    V (Value)      = 0.0 to 1.0 — brightness (we handle this separately)

    Returns: (R, G, B) each 0 to 255

    The math divides the color wheel into 6 sectors of 60 degrees each:
      0-60    Red to Yellow
      60-120  Yellow to Green
      120-180 Green to Cyan
      180-240 Cyan to Blue
      240-300 Blue to Magenta
      300-360 Magenta to Red
    """
    h = h % 360          # Keep hue in 0-360 range using modulus
    c = v * s            # Chroma (color intensity)
    x = c * (1 - abs((h / 60) % 2 - 1))  # Secondary color component
    m = v - c            # Base brightness offset

    # Determine RGB based on which 60 degree sector hue falls in
    if   h < 60:  r, g, b = c, x, 0
    elif h < 120: r, g, b = x, c, 0
    elif h < 180: r, g, b = 0, c, x
    elif h < 240: r, g, b = 0, x, c
    elif h < 300: r, g, b = x, 0, c
    else:         r, g, b = c, 0, x

    # Scale from 0-1 to 0-255 and add base offset
    return int((r + m) * 255), int((g + m) * 255), int((b + m) * 255)


def hue_to_name(h):
    """
    Return approximate color name for a given hue angle.
    These are ranges, not exact values — every angle in between
    is a valid color, just shown with the nearest English name.

    Example: hue=23 is Orange, hue=47 is Yellow, hue=200 is Cyan
    """
    h = h % 360
    if   h < 15  or h >= 345: return "Red"
    elif h < 45:               return "Orange"
    elif h < 75:               return "Yellow"
    elif h < 150:              return "Green"
    elif h < 195:              return "Cyan"
    elif h < 255:              return "Blue"
    elif h < 285:              return "Purple"
    elif h < 345:              return "Pink"
    return "Red"


def read_joystick():
    """
    Read joystick X and Y axes and return normalized values.

    Raw ADC value: 0 to 65535
    After subtracting center (32768): -32768 to +32767
    After deadzone + normalization:   -1.0 to +1.0

    Deadzone: ignore tiny movements near center to prevent
    the LED from flickering when joystick is resting still.
    """
    # Read raw values and subtract center to get deviation from center
    raw_x = joy_x.value - JOYSTICK_CENTER
    raw_y = joy_y.value - JOYSTICK_CENTER

    # Apply deadzone — set to 0 if movement is too small to matter
    if abs(raw_x) < JOYSTICK_DEADZONE: raw_x = 0
    if abs(raw_y) < JOYSTICK_DEADZONE: raw_y = 0

    # Normalize to -1.0 to +1.0 and clamp to valid range
    norm_x = max(-1.0, min(1.0, raw_x / JOYSTICK_MAX))
    norm_y = max(-1.0, min(1.0, raw_y / JOYSTICK_MAX))

    return norm_x, norm_y


def update_oled(color_name, r, g, b, brightness, saturation, mode, sat_mode):
    """
    Refresh OLED display with current state.
    Display is 128x32 pixels — fits exactly 3 lines of text at size 1.

    oled.fill(0)             → clear screen to black (0=black, 1=white)
    oled.text(str, x, y, 1) → draw white text at pixel position x, y
    oled.show()              → push buffer to physical screen
    """
    oled.fill(0)  # Clear screen before redrawing everything

    # Line 1 (y=0): Show current mode, or SAT MODE if saturation active
    if sat_mode:
        oled.text("SAT MODE", 0, 0, 1)
    else:
        oled.text(MODE_NAMES[mode], 0, 0, 1)

    # Line 2 (y=10): Current color name
    oled.text("Color: " + color_name, 0, 10, 1)

    # Line 3 (y=20): RGB values on left side
    oled.text("R:{} G:{} B:{}".format(r, g, b), 0, 20, 1)

    # Right side of line 3: saturation % in sat mode, brightness % otherwise
    if sat_mode:
        oled.text("S:{}%".format(int(saturation * 100)), 95, 20, 1)
    else:
        oled.text("{}%".format(int(brightness * 100)), 100, 20, 1)

    oled.show()  # Push all drawn content to the physical OLED screen


def millis():
    """
    Return current time in milliseconds since program started.
    Used for debounce timing — same concept as millis() in Arduino C++.
    time.monotonic() returns seconds as a float, multiply by 1000 for ms.
    """
    return int(time.monotonic() * 1000)


# ─────────────────────────────────────────────────────────────────────────────
# STARTUP SEQUENCE
# ─────────────────────────────────────────────────────────────────────────────

# Show splash screen for 2 seconds so user knows board is powered on
oled.fill(0)
oled.text("RGB Micropad", 10, 5, 1)
oled.text("by Rishaan D.", 10, 18, 1)
oled.show()
time.sleep(2)

# Set initial LED color (Red at full brightness and saturation)
set_led(r, g, b, brightness)

# Draw initial OLED state
update_oled(color_name, r, g, b, brightness, saturation, mode, sat_mode)


# ─────────────────────────────────────────────────────────────────────────────
# MAIN LOOP — runs forever, approximately 20 times per second (50ms per loop)
# ─────────────────────────────────────────────────────────────────────────────

while True:

    # Get current timestamp at start of each loop
    # Used for all debounce time calculations this iteration
    now = millis()

    # ── BUTTON SW1 — Toggle Mode (Color vs Brightness) ───────────────────────
    sw1_val = sw1.value  # True = not pressed, False = pressed (pull-up logic)

    if (not sw1_val               # Button IS pressed right now
    and sw1_last                  # Button was NOT pressed last loop
    and (now - sw1_debounce) > DEBOUNCE_MS):  # 200ms passed since last press

        # Ternary operator: toggle between modes
        # "Set mode to BRIGHTNESS if currently COLOR, otherwise set to COLOR"
        mode = MODE_BRIGHTNESS if mode == MODE_COLOR else MODE_COLOR
        sw1_debounce = now        # Reset debounce timer

    sw1_last = sw1_val            # Save state for next loop comparison


    # ── BUTTON SW2 — Cycle Color Presets ─────────────────────────────────────
    sw2_val = sw2.value

    if (not sw2_val
    and sw2_last
    and (now - sw2_debounce) > DEBOUNCE_MS):

        # Advance preset index, wrap to 0 using modulus when end is reached
        # Example: (7 + 1) % 8 = 0 → wraps from last preset back to first
        preset_index = (preset_index + 1) % len(PRESETS)

        # Unpack tuple into 4 variables: name, R, G, B
        color_name, r, g, b = PRESETS[preset_index]

        # Update LED immediately with new preset color
        set_led(r, g, b, brightness)
        sw2_debounce = now

    sw2_last = sw2_val


    # ── JOYSTICK BUTTON — Toggle Saturation Mode ──────────────────────────────
    joy_sw_val = joy_sw.value

    if (not joy_sw_val            # Joystick button IS pressed right now
    and joy_sw_last               # Was NOT pressed last loop
    and (now - joy_sw_debounce) > DEBOUNCE_MS):

        # Toggle saturation mode: False becomes True, True becomes False
        sat_mode = not sat_mode
        joy_sw_debounce = now

    joy_sw_last = joy_sw_val


    # ── READ JOYSTICK AXES ────────────────────────────────────────────────────
    joy_norm_x, joy_norm_y = read_joystick()  # Returns -1.0 to +1.0


    # ── COLOR MODE ────────────────────────────────────────────────────────────
    if mode == MODE_COLOR:

        if sat_mode:
            # SATURATION SUB-MODE: Y axis controls saturation only
            # Push joystick up = more vivid, down = more grey/white
            if abs(joy_norm_y) > 0:
                saturation += joy_norm_y * 0.02           # Small step per loop
                saturation = max(0.0, min(1.0, saturation))  # Clamp 0.0-1.0
                r, g, b = hsv_to_rgb(hue, saturation)     # Recalculate RGB
                set_led(r, g, b, brightness)

        else:
            # NORMAL COLOR MODE: joystick angle maps directly to hue
            # math.atan2(y, x) calculates the angle of the joystick vector
            # Result is in radians (-pi to pi), convert to degrees (0-360)
            if abs(joy_norm_x) > 0 or abs(joy_norm_y) > 0:
                angle = math.atan2(joy_norm_y, joy_norm_x) # Radians -pi to pi
                hue = (math.degrees(angle) + 360) % 360    # Convert to 0-360
                r, g, b = hsv_to_rgb(hue, saturation)      # RGB from hue+sat
                color_name = hue_to_name(hue)              # Name for display
                set_led(r, g, b, brightness)


    # ── BRIGHTNESS MODE ───────────────────────────────────────────────────────
    elif mode == MODE_BRIGHTNESS:

        # Y axis only: push up = brighter, push down = dimmer
        if abs(joy_norm_y) > 0:
            brightness += joy_norm_y * 0.02               # Small step per loop
            brightness = max(0.0, min(1.0, brightness))   # Clamp 0.0-1.0
            set_led(r, g, b, brightness)


    # ── UPDATE OLED DISPLAY ───────────────────────────────────────────────────
    # Refresh every loop so display always shows current state
    update_oled(color_name, r, g, b, brightness, saturation, mode, sat_mode)


    # ── LOOP TIMING ───────────────────────────────────────────────────────────
    # 50ms delay = 20 loops per second
    # Fast enough to feel responsive, slow enough to save power
    time.sleep(0.05)

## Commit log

2026-05-25 Initial PCB commit - RGB Micropad complete
    [rgb_led_controller-B_Cu.gbr, rgb_led_controller-B_Mask.gbr, rgb_led_controller-B_Paste.gbr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]
2026-05-25 RGB micropad update - new design with module errors fixed
    [rgb_led_controller.kicad_pcb]
2026-05-25 Reorganized repo for Blueprint submission
    [rgb_led_controller-B_Cu.gbr, rgb_led_controller-B_Mask.gbr, rgb_led_controller-B_Paste.gbr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]
2026-05-25 Cleaned root - removed loose files, added missing folders
    [rgb_led_controller-B_Cu.gbr, rgb_led_controller-B_Mask.gbr, rgb_led_controller-B_Paste.gbr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]
2026-05-25 Add README for RGBmicro hackpad project
    Added detailed information about the RGBmicro hackpad, including features, operation, PCB details, sizes, firmware, BOM, and future plans.
2026-06-04 Added complete Fusion 360 case - top plate and bottom case with branding
    [RGBMicropad_Bottom.step, RGBMicropad_Top.step, rgb_led_controller-Edge_Cuts.dxf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]
2026-06-04 Enhance README with BOM, assembly, and devlog
    Updated README.md to include additional BOM details, steps to reproduce, and devlog entries.
2026-06-05 Added schematic and PCB layout PDFs to Images folder
    [rgb_led_controller.kicad_sch]
2026-06-05 Updated silkscreen labels, re-exported Gerbers, fixed README
    [rgb_led_controller-B_Cu.gbr, rgb_led_controller-B_Mask.gbr, rgb_led_controller-B_Paste.gbr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]
2026-06-06 Added full assembly screenshot, f3z source file, BOM.csv
    [rgb_led_controller.step, rgb_led_controller.stl, rgb_micropad_case.f3z]
2026-06-06 Resistor value chart added to BOM
2026-06-06 Cleaned up junk files, added gitignore, added purpose to readME
    [rgb_led_controller-Edge_Cuts.dxf, rgb_led_controller.stl]
2026-06-08 Revise README for RGB micro hackpad project
    Updated README.md to include project details, features, and assembly instructions for the RGB micro hackpad.
2026-06-10 Add combined STEP file with OLED and joystick models
    [RGBMicropad_Bottom.step, RGBMicropad_Top.step, micropad_combined.step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]
2026-06-12 Fix silkscreen inaccuracies
    [rgb_led_controller-B_Cu.gbr, rgb_led_controller-B_Mask.gbr, rgb_led_controller-B_Paste.gbr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]
